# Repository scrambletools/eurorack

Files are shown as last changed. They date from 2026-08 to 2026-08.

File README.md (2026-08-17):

# Synthia — Eurorack Interposer for the Scramble Hat-trik

A 2-layer PCB (~85 × 30 mm) that turns the **ESP32-P4-ETH carrier +
Scramble Hat-trik** stack into a eurorack module: rack power, panel audio
I/O, and a display socket, with no changes to either board.

```
        ┌───────────────┐
        │  Scramble Hat │   (mounted 180° opposite the carrier)
        ├─ J4/J5 male ──┤
        │   THIS BOARD  │──▶ 10-pin eurorack power in, 5 V buck out,
        ├─ J2/J3 female─┤     3.5 mm in/out jacks, I²C display socket
        │  ESP32-P4-ETH │
        └───────────────┘
```

## Features

1. **Eurorack power** (J1, 2×5 shrouded IDC): +12 V from the bus through
   reverse-polarity protection (D1) and a ferrite (FB1) into a
   K7805-1000R3 buck (U1) → **5 V** injected into the mezzanine, powering
   the carrier and the hat. −12 V feeds the output amplifier (D2 + FB2
   conditioned).
2. **Hat interposer** (J2/J3 bottom-side sockets down to the carrier;
   J4/J5 headers up to the hat): a full 7+7 pass-through, cross-wired so
   the hat mounts 180° opposite its normal orientation.
3. **Panel audio** (J6 in, J7 out — 3.5 mm mono threaded jacks) to header
   J8, which direct-mates the hat's J7 socket. **Eurorack-levelled both
   ways**: the input is padded −11.5 dB (R2/R3 100k/39k — ±5 V modular
   swings land inside the hat's codec range) and the output is amplified
   ×4.9 by a TL072 on the rack's ±12 V rails (hat's ~2 Vpp → ~10 Vpp
   modular level, 1 kΩ series out).
4. **Display socket** (J10): GND / 3V3 / SCL / SDA for an SSD1306-style
   I²C OLED, powered and driven directly from this board — the hat's J6
   header is not needed.

## Usage notes

- **USB-C works while the module is rack-powered** (bench-verified): the
  buck injects on the carrier's pre-mux node (`VCC1_5V`, the same one the
  PoE module drives), so the carrier's own power mux disconnects USB
  VBUS automatically and only USB *data* + the UART chip stay active.
  One caveat: with the **rack off** and USB still plugged, USB back-feeds
  the buck's output — tolerated in practice but unspecified for the
  K7805; unplug one or the other when parked, or add an ideal diode
  (LM66100, LCSC C2869734) in the buck's output if you want it bulletproof.
- **Phantom power doesn't exist in the rack** (no PoE), so the hat's XLR
  condenser path is out of scope here — the module's jacks use the
  instrument input and line output instead.
- **Hat build for eurorack:** populate **J7 + R27**; leave **J1 (combo
  jack), SW1 and J6 unpopulated**.
- **Levels:** handled on-board. Input: R2/R3 (100k/39k, ≈ −11.5 dB) pads
  ±5 V modular signals into the hat's codec range. Output: U2 (TL072,
  ±12 V) amplifies the hat's ~2 Vpp to ~10 Vpp modular level with a 1 kΩ
  series output. For non-modular sources into J6 (guitar level), swap
  R2 to 0 Ω and leave R3 off — that restores the hat's native
  instrument-level path.

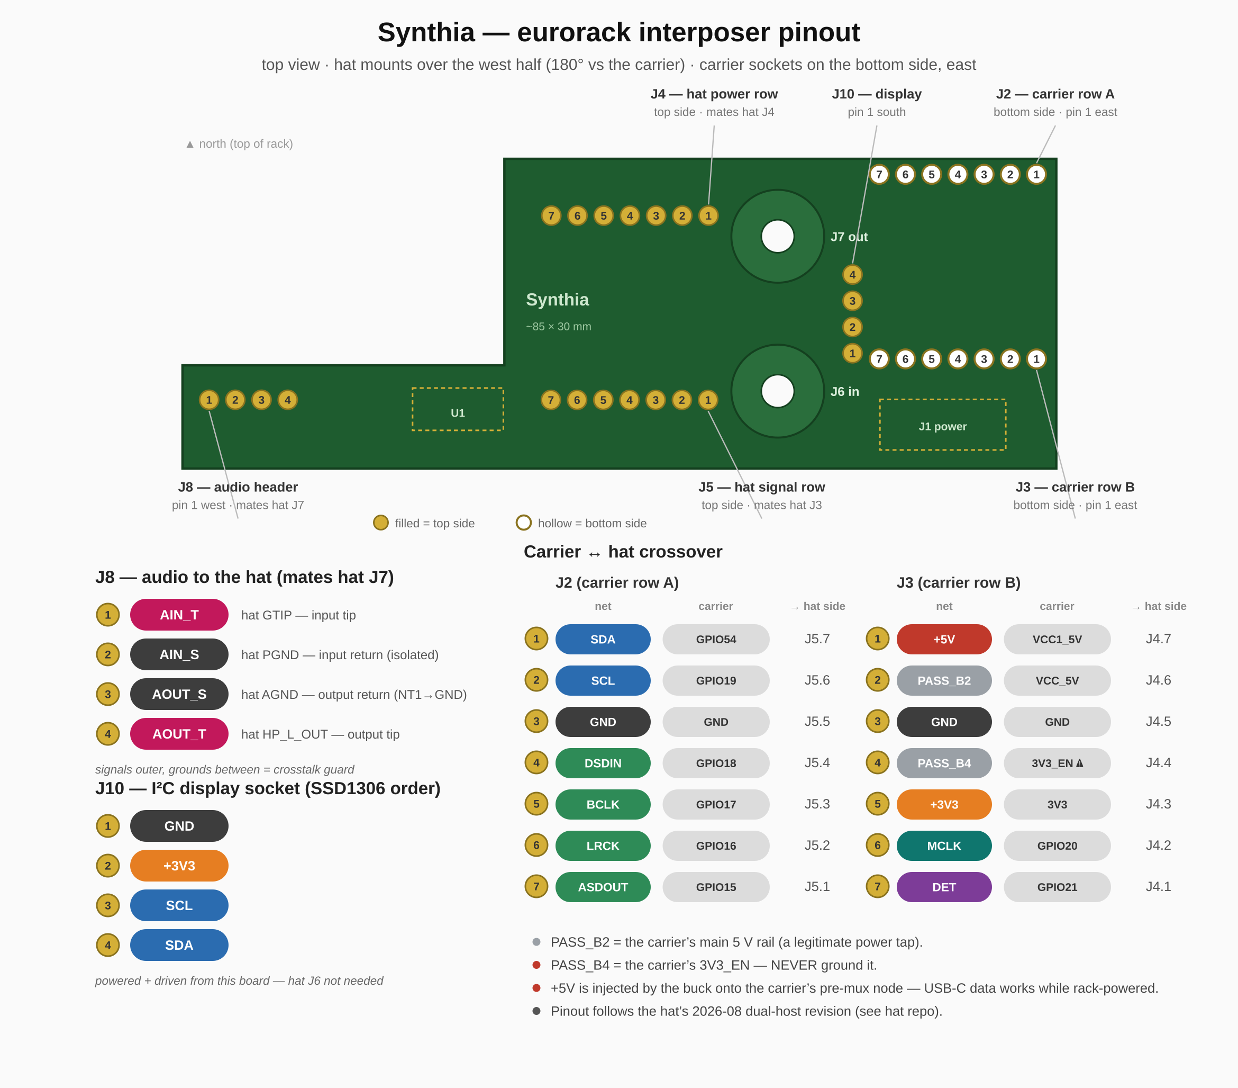
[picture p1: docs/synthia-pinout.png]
Synthia pinout


## Mezzanine crossover map

J4 sits directly above J2, J5 above J3, all pin 1s oriented the same way.
Because the hat mounts 180° opposite the carrier, the pin order reverses;
the routing un-scrambles it:

| This J2 (carrier row A) | net | → appears on | This J3 (carrier row B) | net | → appears on |
|---|---|---|---|---|---|
| 1 | SDA | J5.7 | 1 | +5V | J4.7 |
| 2 | SCL | J5.6 | 2 | PASS_B2 | J4.6 |
| 3 | GND | J5.5 | 3 | GND | J4.5 |
| 4 | DSDIN | J5.4 | 4 | PASS_B4 | J4.4 |
| 5 | BCLK | J5.3 | 5 | +3V3 | J4.3 |
| 6 | LRCK | J5.2 | 6 | MCLK | J4.2 |
| 7 | ASDOUT | J5.1 | 7 | DET | J4.1 |

This follows the hat's 2026-08 mezzanine pinout revision (Pico-compatible;
see the hat README). Carrier firmware pin constants: SDA = GPIO54,
SCL = GPIO19, DSDIN = GPIO18, BCLK = GPIO17, LRCK = GPIO16,
ASDOUT = GPIO15, MCLK = GPIO20, DET = GPIO21.

PASS_B2/PASS_B4 are unused by the hat but bench-tracing identified them
on the carrier: **PASS_B2 = the carrier's main 5 V rail** (downstream of
its ORing diode — a legitimate power tap) and **PASS_B4 = the carrier's
3V3_EN** — **never ground it**, that would kill the carrier's 3.3 V rail.

## Audio to the hat (J8)

J8 direct-mates the hat's J7 socket (same 8.5 mm stacking series as the
mezzanine, so all connectors seat together). Pin-for-pin when mated:

| J8 pin | net | hat J7 pin / net | note |
|---|---|---|---|
| 1 | AIN_T | 1 `GTIP` | input tip |
| 2 | AIN_S | 2 `PGND` | input ground |
| 3 | AOUT_S | 3 `AGND` | output ground |
| 4 | AOUT_T | 4 `HP_L_OUT` | output tip (left channel) |

Signals sit on the outer pins with both grounds between them — deliberate
crosstalk guarding; keep the order if anything gets re-pinned. Fallback:
the same pins can be hand-wired to the hat's J1/J2 pads with shielded
cable (see the hat README).

**Grounding:** the input side stays fully isolated (sleeve → hat PGND,
passive divider only). The output side is driven by the ±12 V amplifier,
so its return (AOUT_S / hat AGND) is bonded to module GND at **one
deliberate point** (net-tie NT1 beside the amp) — AIN_S and AOUT_S are
still never joined to each other. The jacks **must have plastic threaded noses** so the
metal faceplate doesn't short the two sleeves together — don't substitute
metal-bushing jacks.

## Jacks

XKB **PJ-3410** (LCSC C5146694) — a **vertical** PCB jack: nose points
straight up, ~19.5 mm above the PCB; plastic threaded nose M7.7 × 0.75;
faceplate hole ≥ 7.8 mm (larger than a Thonkiconn's 6 mm). **Bench-verify
the pad map (T/S/TN) with a meter on a sample before ordering boards** —
it was derived from the vendor footprint, not measured. Terminal 3 is
intentionally unconnected.

## Power header

J1 pins 1–2 = **−12 V** (red-stripe end), 3–8 = GND, 9–10 = +12 V. D1
blocks a reversed ribbon from applying −12 V to the buck.

## Layout notes (as built)

- Carrier sockets at the east edge (the carrier extends below/east); the
  hat mounts over the west half, overhanging the south edge. Constrained
  placements can be re-derived against the hat file with
  `tools/map_hat.py`.
- Audio runs are tight signal+return pairs (input along the south edge,
  output around the north), input and output ≥ 7 mm apart, attenuator at
  the J8 end. A single B.Cu ground pour covers the power/crossover
  region; the audio island is pour-free. Coupling audit passed.

## Repository layout

| Path | Contents |
|---|---|
| `eurorack.kicad_sch` / `.kicad_pcb` | schematic + layout |
| `BOM.csv` | bill of materials — single source of truth |
| `fab/` | JLCPCB gerbers, drills, BOM, CPL — see [`fab/README.md`](fab/README.md) |
| `tools/gen_fab.py` | regenerate the production files |
| `tools/map_hat.py` | derive hat-constrained placements from the hat PCB |
| `docs/` | schematic + silkscreen PDFs |
| `lib/` | project footprints + 3D models (PJ-3410) |
| `synthia-v1.step`, `faceplate.step` | board / faceplate models (untracked; regenerate with `kicad-cli pcb export step --subst-models`) |

## Status

The I/O stage is placed, routed and DRC-clean. **Schematic is ahead of
the PCB on one item**: the hat's 2026-08 mezzanine pinout revision. The
crossover copper is untouched (the runs just carry new net names after
Update-PCB-from-Schematic), but the **J10 display SCL/SDA stubs must be
re-routed** — I²C moved from the J3.6/J3.7 ↔ J4.2/J4.1 runs (now
MCLK/DET) to the J2.2/J2.1 ↔ J5.6/J5.7 runs. Regenerate fab/docs
afterwards. Before ordering: bench-verify the PJ-3410 pad map, and
caliper-check the carrier's mezzanine row spacing against J2/J3
(designed 17.75 mm; the fit-proven hat uses 17.577 mm).

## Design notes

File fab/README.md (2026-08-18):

# Eurorack Interposer — Fabrication Files

Production files for **JLCPCB**. 2-layer board, ~84.7 × 30 mm.

| File | Purpose |
|---|---|
| `eurorack-gerbers.zip` | **PCB fab** — gerbers + drills (upload this) |
| `eurorack-BOM.csv` / `.xlsx` | **Assembly BOM** — every part (SMD + THT) |
| `eurorack-CPL.csv` | Placement file — every assembled part |

## Assembly

**JLCPCB places everything** — 28 placements: the 18 SMD parts
(`C1–C7`, `D1/D2`, `FB1/FB2`, `R2–R7`, `U2`) plus all through-hole
(`J1` power IDC, `J2/J3` carrier sockets, `J4/J5` hat headers,
`J6/J7` panel jacks, `J8`, `J10`, `U1` K7805 buck). Notes:

- THT sits on **both sides** (top: J4/J5/J6/J7/J8/J10; bottom:
  J1/J2/J3/U1) — expect JLC to quote the THT as hand-soldered on
  their line at checkout.
- **Verify orientation in the preview** — no validated rotation
  corrections exist for this board: `D1/D2` (SMA cathode band),
  `U2` (SOIC-8 pin 1), `J1` (shroud key toward the marked −12 V end),
  `U1` (K7805 pin 1 = Vin), `J6/J7` (asymmetric jack pad pattern).
- Excluded from assembly: `NT1` only (net tie — copper, not a part).
- **DNP:** none. (R2/R3 = 100k/39k eurorack input pad; for guitar-level
  sources instead fit R2 = 0 Ω and omit R3 — see root README.)

## Before ordering

- Bench-verify the PJ-3410 jack pad map (T/S/TN) with a meter on a sample.
- Caliper-check the carrier's mezzanine row spacing against J2/J3
  (designed at 17.75 mm; the fit-proven hat uses 17.577 mm — see root README).

Regenerate everything with `python3 tools/gen_fab.py` (KiCad closed).

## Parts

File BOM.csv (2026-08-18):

Comment | Designator | Qty | MPN | Manufacturer | Footprint | LCSC Part # | JLCPCB Class | Mount | DNP | Unit Price USD | Notes | Datasheet
Eurorack power header 2x5 shrouded IDC | J1 | 1 | 2.54-2*5P | BOOMELE | IDC box 2x5 P2.54mm | C5665 | Extended | THT |  | 0.0801 | Red-stripe (-12V) end = pins 1/2; mark on silk | https://assets.lcsc.com/datasheet/szlcsc/Download-ISO9001-Certification.pdf
5V/1A buck module (7805 drop-in) | U1 | 1 | K7805-1000R3 | YLPTEC | SIP-3 (TSR-1 land, P2.54) | C2992391 | Extended | THT |  | 2.04 | Vin 8-36V; pin 1=Vin 2=GND 3=Vout | https://datasheet.lcsc.com/datasheet/pdf/313b6b20c299036ba7ffc00b257b15b5.pdf?productCode=C2992391
Schottky reverse protection 40V 3A | D1, D2 | 2 | SS34 | MDD | SMA (DO-214AC) | C8678 | Basic | SMT |  | 0.0352 | D1 = +12V, D2 = -12V reverse protection | https://datasheet.lcsc.com/datasheet/pdf/dfa1ff67dea875d0135103ba9ada713a.pdf?productCode=C8678
22uF 25V X5R | C1, C3, C7 | 3 | GRT21BR61E226ME13L | Murata | 0805 | C398931 | Extended | SMT |  | 0.1657 | C1/C3 buck in/out bulk; C7 = -12V bulk at U2. JLC-basic Samsung equivalents out of stock 2026-07-23 | https://datasheet.lcsc.com/datasheet/pdf/e6bf9871bf3c14261c20e97c8b0fc691.pdf?productCode=C398931
100nF 50V X7R | C2, C4, C5, C6 | 4 | CC0402KRX7R9BB104 | Yageo | 0402 | C131394 | Basic | SMT |  | 0.0097 | Buck + op-amp rail decoupling. Same part as hat BOM | https://datasheet.lcsc.com/datasheet/pdf/23ccee80ee542e7cf156a772bb589942.pdf?productCode=C131394
Ferrite bead 600R@100MHz 2A | FB1, FB2 | 2 | MPZ2012S601AT000 | TDK | 0805 | C21519 | Basic | SMT |  | 0.0296 | FB1 = +12V, FB2 = -12V rail bead | https://datasheet.lcsc.com/datasheet/pdf/faf431921010bd6151d84a7da591b5d1.pdf?productCode=C21519
100k 1% | R2, R7 | 2 | RC0402FR-07100KL | YAGEO | 0402 | C60491 | Basic | SMT |  | 0.0061 | R2 = input attenuator series (with R3 = -11.5dB: 10Vpp -> 2.7Vpp); R7 = output amp input bias | https://www.lcsc.com/product-detail/C60491.html
39k 1% | R3, R5 | 2 | RC0402FR-0739KL | YAGEO | 0402 | C137995 | Basic | SMT |  | 0.0055 | R3 = input attenuator shunt; R5 = output amp feedback (x4.9 with R4) | https://www.lcsc.com/product-detail/C137995.html
1x7 female socket 8.5mm stack | J2, J3 | 2 | PM254V-11-07-H85 | XFCN | PinSocket 1x7 P2.54 TH | C2832270 | Extended | THT |  | 0.079 | Same part as hat J3/J4; mates carrier pins | https://datasheet.lcsc.com/datasheet/pdf/5aa023c30ffb4f607882b69ea05af7aa.pdf?productCode=C2832270
1x7 male header | J4, J5 | 2 | PZ254V-11-07P | XFCN | PinHeader 1x7 P2.54 TH | C492406 | Extended | THT |  | 0.0206 | Mates hat J3/J4 sockets; same XFCN family as J2/J3 | https://www.lcsc.com/product-detail/C492406.html
1x4 male header | J8 | 1 | B-2100S04P-A110 | Ckmtw | PinHeader 1x4 P2.54 TH | C124378 | Extended | THT |  | 0.0561 | Direct-mates hat J7 (1x4 female 8.5mm socket, hat-side part C541851); fallback = wires to hat J1/J2 pads | https://datasheet.lcsc.com/datasheet/pdf/219f7e7eb5f34457895b2c164313179f.pdf?productCode=C124378
3.5mm mono jack, horizontal, threaded | J6, J7 | 2 | PJ-3410 | XKB | Vertical THT nose-up, M7.7x0.75 plastic thread | C5146694 | Extended | THT |  | 0.3483 | VERTICAL jack (nose up ~19.5mm); panel hole >=7.8mm; plastic nose keeps sleeve grounds split; BENCH-VERIFY tip/sleeve vs footprint pad map before fab | https://datasheet.lcsc.com/datasheet/pdf/828fa49ea5e7f225aa21ffda61211ee1.pdf?productCode=C5146694
1x4 female socket, 8.5mm | J10 | 1 | PM254V-11-04-H85 | XFCN | PinSocket 1x4 P2.54 TH (H85) | C541851 | Extended | THT |  | 0.0703 | Display socket on main nets: 1=GND 2=+3V3 3=SCL 4=SDA (SSD1306-style order). J9 pass-through deleted during layout - display runs from the module directly, hat J6 not needed. | https://datasheet.lcsc.com/datasheet/pdf/7912db05a9479e06d287e74aeb027dc2.pdf?productCode=C541851
10k 1% | R4 | 1 | RC0402FR-0710KL | YAGEO | 0402 | C60490 | Basic | SMT |  | 0.0059 | Output amp gain set | https://www.lcsc.com/product-detail/C60490.html
1k 1% | R6 | 1 | RC0402FR-071KL | YAGEO | 0402 | C106235 | Basic | SMT |  | 0.0062 | Output series resistor (eurorack-standard output impedance / short protection) | https://www.lcsc.com/product-detail/C106235.html
Dual JFET op-amp | U2 | 1 | TL072CDT | ST | SOIC-8 | C6961 | Extended | SMT |  | 0.1627 | Eurorack output amp x4.9 on +/-12V (2Vpp -> ~10Vpp); half B terminated | https://www.lcsc.com/product-detail/C6961.html

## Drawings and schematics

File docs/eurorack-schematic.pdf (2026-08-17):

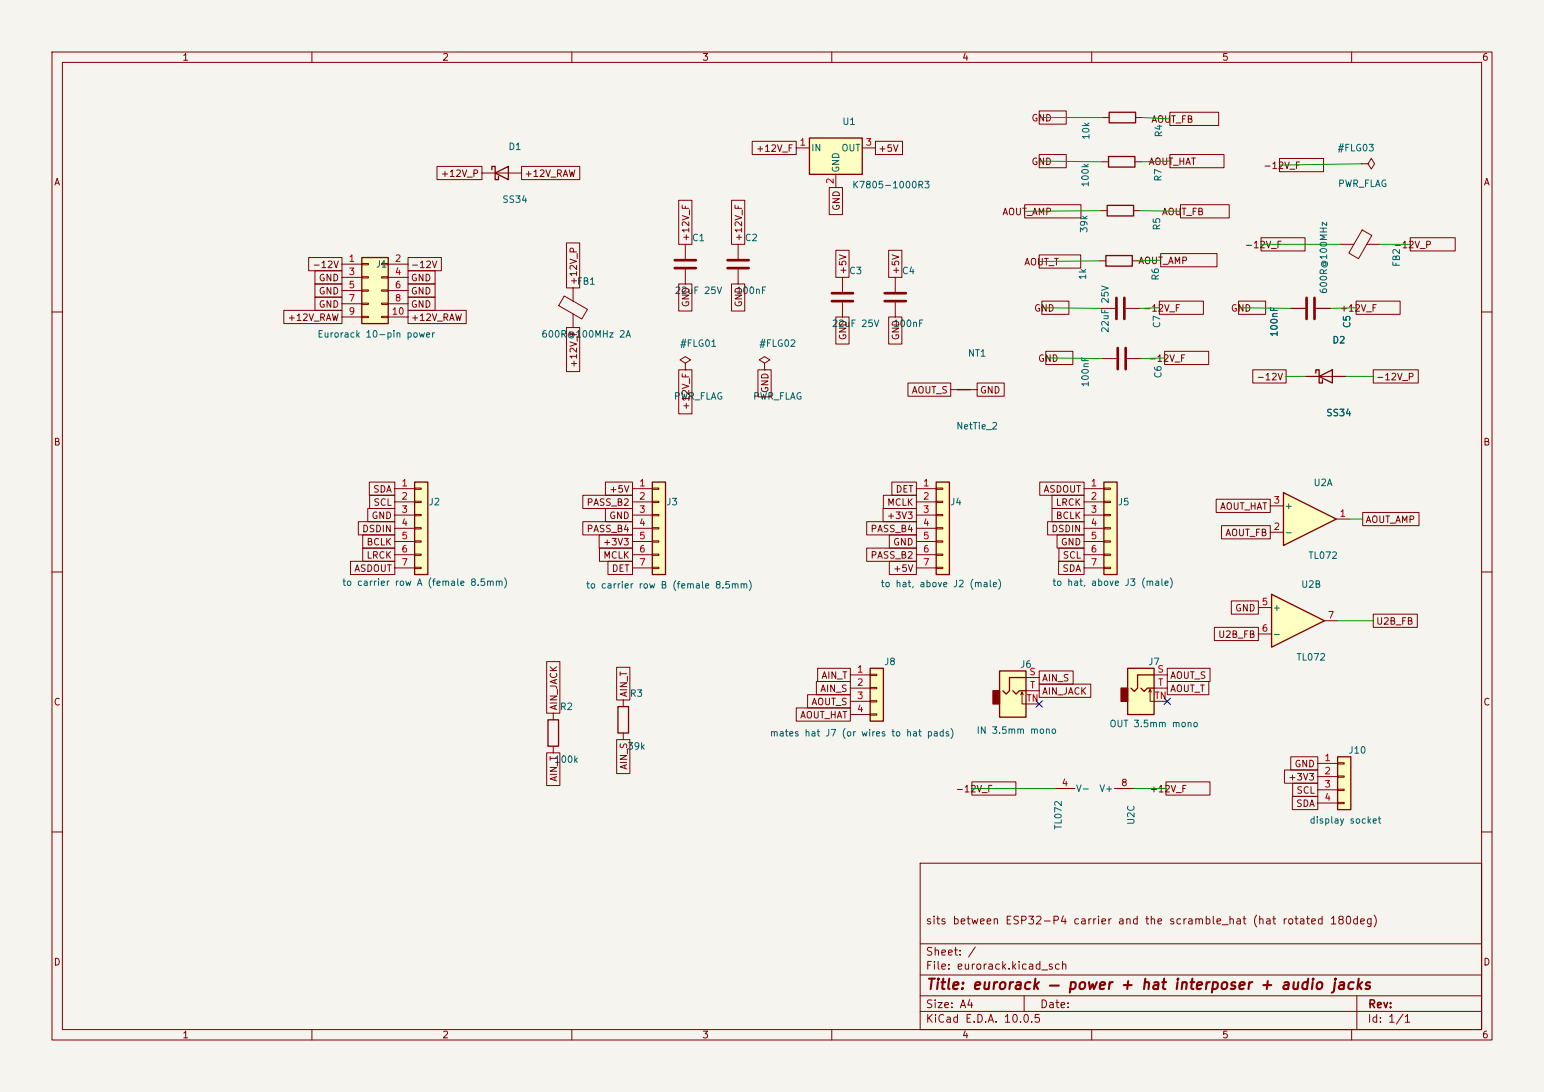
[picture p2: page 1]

to hat, above J2 (male) 1

to carrier row B (female 8.5mm)

sits between ESP32-P4 carrier and the scramble_hat (hat rotated 180deg)

Sheet: /
File: eurorack.kicad_sch
Title: eurorack — power + hat interposer + audio jacks

Size: A4 | Rev:
KiCad E.D.A. 10.0.5 | Id: 1/1

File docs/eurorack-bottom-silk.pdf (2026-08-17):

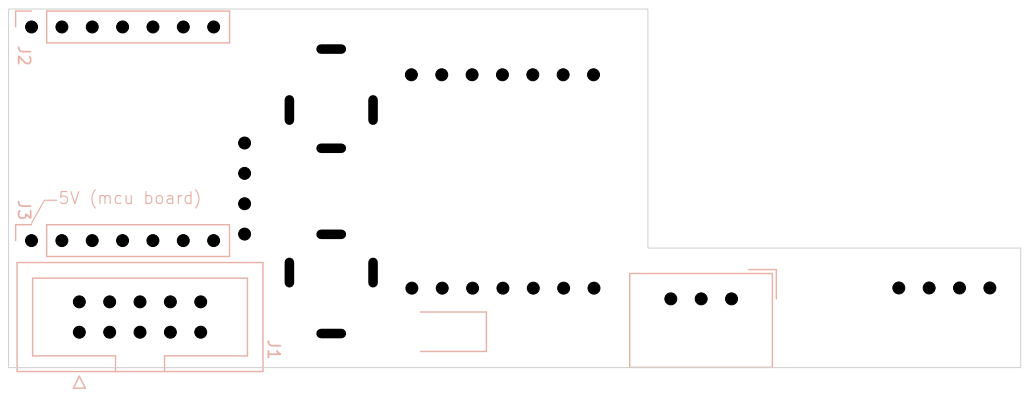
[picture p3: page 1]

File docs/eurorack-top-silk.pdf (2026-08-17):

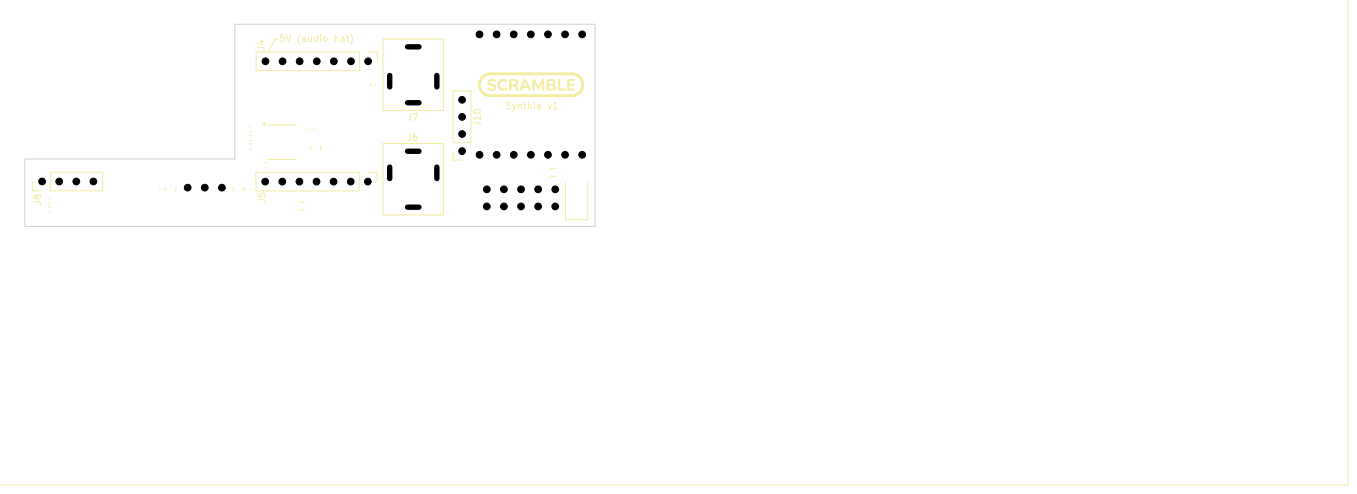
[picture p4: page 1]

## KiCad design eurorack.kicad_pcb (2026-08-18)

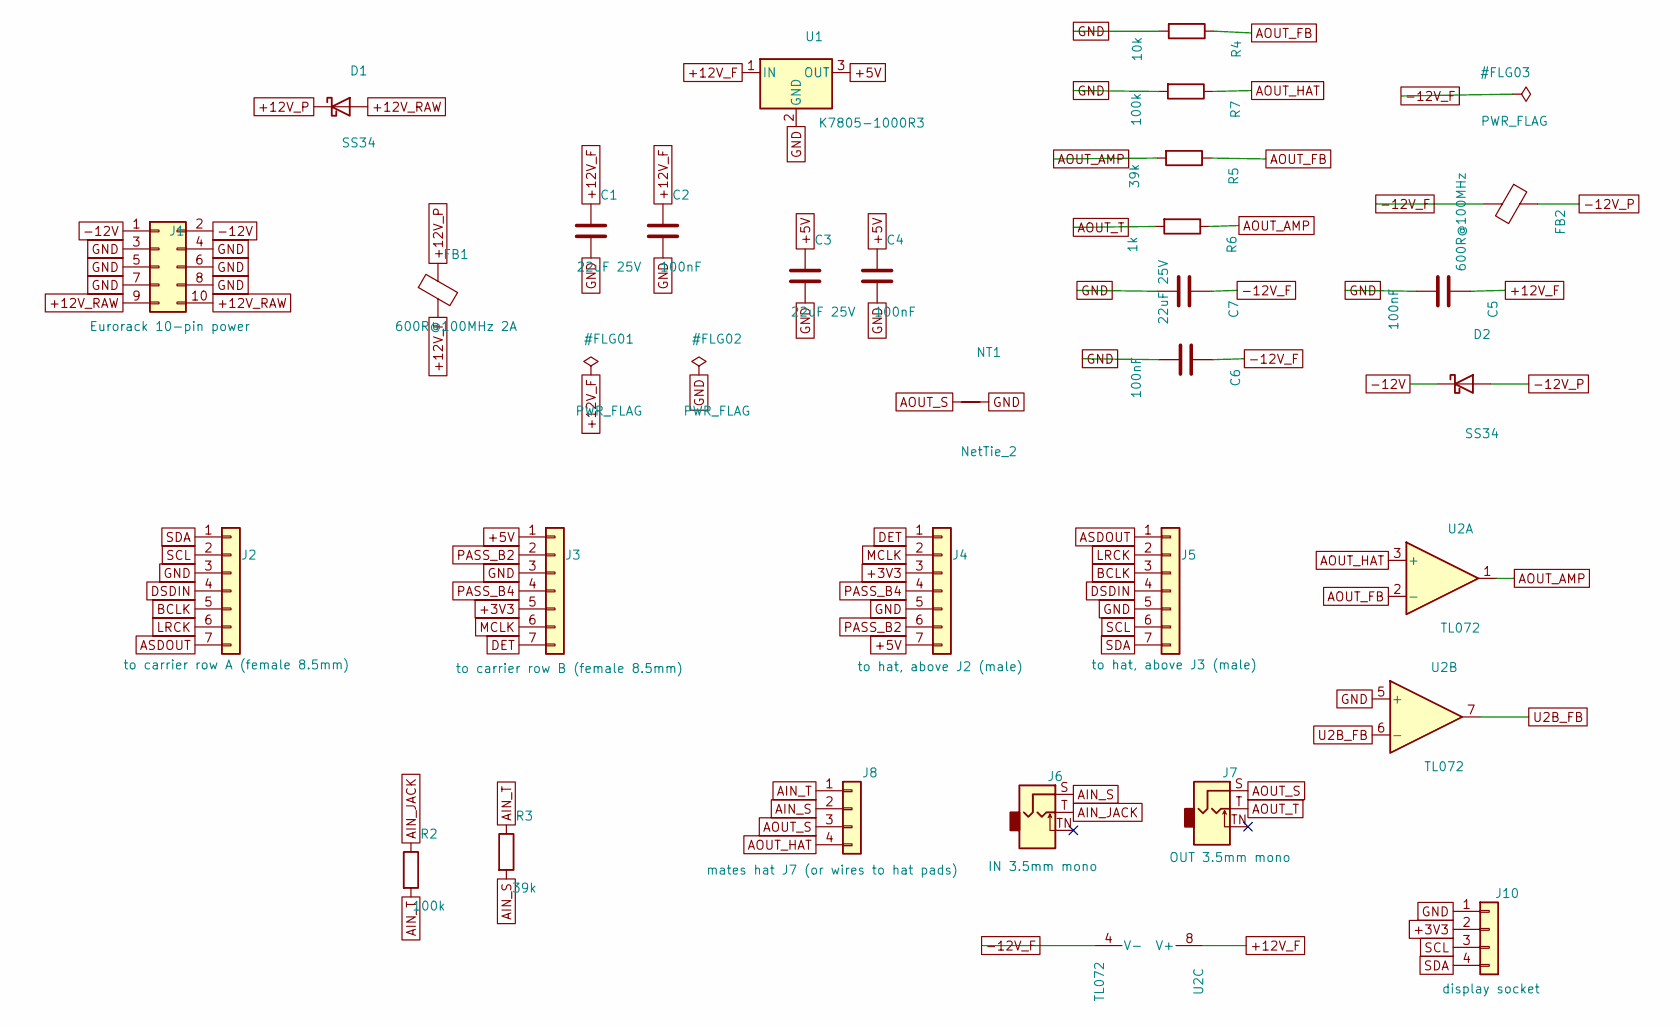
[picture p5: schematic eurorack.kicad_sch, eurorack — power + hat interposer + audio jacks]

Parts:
C1, C3, C7: 22uF 25V; C_0805_2012Metric
C2, C4, C5, C6: 100nF; C_0402_1005Metric
D1, D2: SS34; D_SMA
FB1: 600R@100MHz 2A; L_0805_2012Metric
FB2: 600R@100MHz; L_0805_2012Metric
J1: Eurorack 10-pin power; IDC-Header_2x05_P2.54mm_Vertical
J2: to carrier row A (female 8.5mm); PinSocket_1x07_P2.54mm_Vertical
J3: to carrier row B (female 8.5mm); PinSocket_1x07_P2.54mm_Vertical
J4: to hat, above J2 (male); PinHeader_1x07_P2.54mm_Vertical
J5: to hat, above J3 (male); PinHeader_1x07_P2.54mm_Vertical
J6: IN 3.5mm mono; Jack_3.5mm_Mono_Horizontal_Threaded
J7: OUT 3.5mm mono; Jack_3.5mm_Mono_Horizontal_Threaded
J8: mates hat J7 (or wires to hat pads); PinHeader_1x04_P2.54mm_Vertical
J10: display socket; PinSocket_1x04_P2.54mm_Vertical
NT1: NetTie_2; NetTie-2_SMD_Pad0.5mm
R2, R7: 100k; R_0402_1005Metric
R3, R5: 39k; R_0402_1005Metric
R4: 10k; R_0402_1005Metric
R6: 1k; R_0402_1005Metric
U1: K7805-1000R3; Converter_DCDC_TRACO_TSR-1_THT
U2: TL072; SOIC-8_3.9x4.9mm_P1.27mm

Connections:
+3V3: J3.5, J4.3, J10.2
+5V: C3.1, C4.1, J3.1, J4.7, U1.3 (OUT)
+12V_F: C1.1, C2.1, C5.1, FB1.2, U1.1 (IN), U2.8 (V+)
+12V_P: D1.1 (K), FB1.1
+12V_RAW: D1.2 (A), J1.9, J1.10
-12V: D2.1 (K), J1.1, J1.2
-12V_F: C6.1, C7.1, FB2.2, U2.4 (V-)
-12V_P: D2.2 (A), FB2.1
AIN_JACK: J6.T, R2.1
AIN_S: J6.S, J8.2, R3.2
AIN_T: J8.1, R2.2, R3.1
AOUT_AMP: R5.2, R6.1, U2.1
AOUT_FB: R4.1, R5.1, U2.2 (-)
AOUT_HAT: J8.4, R7.1, U2.3 (+)
AOUT_S: J7.S, J8.3, NT1.1
AOUT_T: J7.T, R6.2
ASDOUT: J2.7, J5.1
BCLK: J2.5, J5.3
DET: J3.7, J4.1
DSDIN: J2.4, J5.4
GND: C1.2, C2.2, C3.2, C4.2, C5.2, C6.2, C7.2, J1.3, J1.4, J1.5, J1.6, J1.7, J1.8, J2.3, J3.3, J4.5, J5.5, J10.1, NT1.2, R4.2, R7.2, U1.2 (GND), U2.5 (+)
LRCK: J2.6, J5.2
MCLK: J3.6, J4.2
PASS_B2: J3.2, J4.6
PASS_B4: J3.4, J4.4
SCL: J2.2, J5.6, J10.3
SDA: J2.1, J5.7, J10.4
U2B_FB: U2.6 (-), U2.7

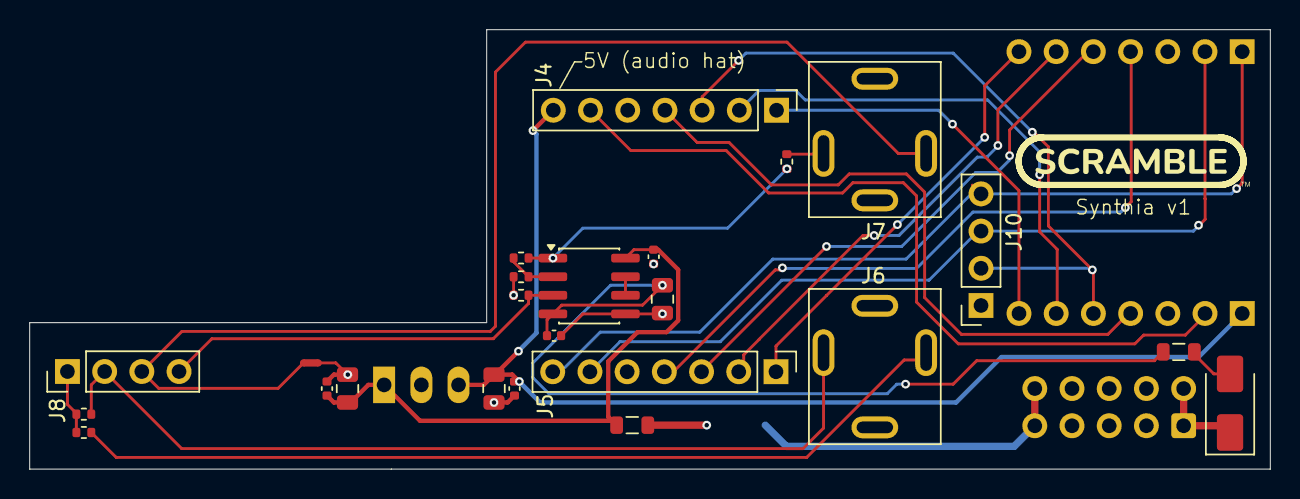
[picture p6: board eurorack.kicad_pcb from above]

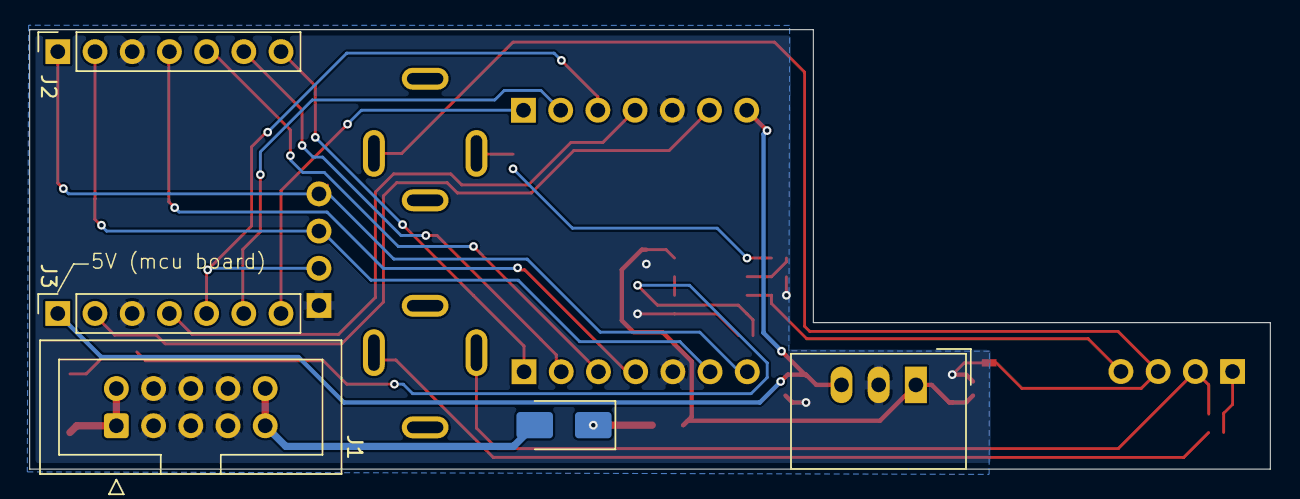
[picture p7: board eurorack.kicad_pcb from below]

Board: 2 copper layers, 84.7 x 30.0 mm, 29 parts (5 on the bottom side), 28 nets.

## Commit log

2026-07-24 eurorack interposer: initial scaffold — schematic, BOM, jack footprint, project files
    [BOM.csv, eurorack.kicad_pcb, eurorack.kicad_sch]
2026-07-24 bom: 0R jumper to in-stock C60485 (C17168 depleted)
    [BOM.csv]
2026-07-24 datasheet links (schematic + BOM), PJ-3410 3D model, R1 2.2k to in-stock C144773
    [BOM.csv, eurorack.kicad_sch]
2026-07-24 jacks: PJ-3410 is a vertical nose-up part — fix footprint outline, 3D model, docs
    [BOM.csv]
2026-07-25 J8 direct-mates hat J7: ground-between-signals pin order (swap 3/4), docs
    [BOM.csv, eurorack.kicad_pcb, eurorack.kicad_sch]
2026-07-28 display pass-through: J9 mates hat J6, J10 display socket, isolated DISP_* nets
    [BOM.csv, eurorack.kicad_pcb, eurorack.kicad_sch]
2026-08-01 layout: place and route the board; drop power LED and J9; display on main nets
    - all nets routed, DRC clean (0 unconnected); audio in/out routed as tight
    signal+return pairs, input and output paths >=7mm apart
    - single B.Cu GND pour over power + crossover; audio island pour-free,
    AIN_S/AOUT_S kept as separate returns end to end
    - DISP_* nets merged into GND/+3V3/SCL/SDA: J10 powers and drives the
    display directly, hat J6 unneeded; J9 pass-through removed as redundant
    - D2/R1 power LED dropped during layout; BOM synced
    [BOM.csv, eurorack.kicad_pcb, eurorack.kicad_sch]
2026-08-01 fab: production files, doc PDFs, placement tool; README overhaul
    - tools/gen_fab.py: gerbers/drills/zip + SMD-only assembly BOM and CPL
    (all THT hand-soldered, R3 DNP); verify D1 (SMA) rotation in preview
    - tools/map_hat.py: derive the hat-constrained placements from the hat pcb
    - docs/: schematic + top/bottom silk PDFs; fab/README ordering guide
    - README: module named Synthia; features, usage notes (no USB while
    rack-powered, levels, hat build options), as-built layout summary
    [eurorack-BOM.csv, eurorack-BOM.xlsx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]
2026-08-01 docs: USB + rack power supported; PASS_B2/PASS_B4 identified on the carrier
    - bench-verified: mezzanine +5V = carrier VCC1_5V (PoE-module node,
    pre-ORing-diode, mux-sensed) - USB VBUS is cut automatically while the
    buck is up; USB data + UART unaffected
    - caveat: rack-off + USB-plugged back-feeds the buck output; LM66100
    (C2869734) noted as optional guard
    - PASS_B2 = carrier main 5V rail; PASS_B4 = carrier 3V3_EN (never ground)
2026-08-01 pcb: relocate buck to bottom side, extend GND pour over it; regen fab + docs
    - U1 (K7805) moved to B.Cu on the west half with C1-C4/FB1 following,
    clearing the hat overhang; +5V rerouted, cap spacing fixed
    - GND pour extended west over the buck cluster (return currents in
    copper, clear of both audio pairs); coupling audit re-passed, DRC clean
    - regen gerbers/BOM/CPL, doc PDFs, board STEP; drop stale faceplate.svg
    [eurorack-BOM.xlsx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]
2026-08-01 pcb: +3V3 reroute; regen fab + docs
    [eurorack-BOM.xlsx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]
2026-08-01 silk: restore logo; regen fab + docs
    [eurorack-BOM.xlsx, eurorack.kicad_pcb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]
2026-08-01 pcb: +5V touch-up; regen fab + docs
    [eurorack-BOM.xlsx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]
2026-08-02 sch+pcb: eurorack I/O stage — input pad 100k/39k, TL072 x4.9 output amp on ±12V
    - input divider now populated (R2/R3 = 100k/39k, -11.5dB): ±5V modular
    swings land inside the hat codec range; also protects against CV/gate
    mis-patches. Guitar-level alternative (R2=0R, R3 off) documented
    - output: TL072 (C6961) x4.9 on +12V_F and a newly conditioned -12V rail
    (D2 SS34 + FB2 bead + 100n/22u), hat ~2Vpp -> ~10Vpp modular level,
    1k series out; spare half terminated; AOUT_S bonded to GND at one
    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
    [BOM.csv, eurorack-BOM.csv, eurorack-BOM.xlsx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]
2026-08-17 sch+pcb: follow hat dual-host pinout — crossover net renames, J10 display taps moved to row-A I2C runs; regen fab + docs; add pinout graphic
    [eurorack-BOM.xlsx, eurorack.kicad_pcb, eurorack.kicad_sch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]
2026-08-17 docs: pinout graphic now drawn on the true L-shaped board outline with per-connector positions and top/bottom-side markers
2026-08-18 pcb: crossover routing touch-ups (DET/ASDOUT/LRCK runs); regen copper gerbers
    [eurorack.kicad_pcb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]
2026-08-18 fab: drop NT1 (net tie, copper-only) from the CPL — JLC rejected the placement with no matching BOM line
    [eurorack.kicad_pcb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]
2026-08-18 fab: full JLC assembly — THT parts join BOM+CPL (28 placements); J4/J5 now a real 1x7 header (XFCN PZ254V-11-07P, C492406) instead of snap-from-strip
    [BOM.csv, eurorack-BOM.csv, eurorack-BOM.xlsx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]
